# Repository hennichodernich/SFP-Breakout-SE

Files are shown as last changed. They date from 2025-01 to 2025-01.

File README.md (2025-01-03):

# Modified SFP-Breakout-Board

This is a modified version of Anders Wallins SFP Breakout Board https://github.com/aewallin/SFP-Breakout-Board

Like the original this works as a SFP fibre-optical transciever simple breakout board up to at least 1 Gbit/s.

What's changed is that is has
* single-ended TX and RX outputs/inputs with SMA connectors (similar to Anders' SFP2SMA_2018.03 board, but with LVDS/LVPECL converters instead of baluns and op amps)
* different (cheaper) LDO

What's unchanged is
* connector and cage for SFP or SFP+ transciever
* +3V3 power for transciever
* Three status LEDs for TX_FAULT, LOS, and MOD_ABS
* jumpers for SFP rate-select settings.

Licensed under CERN OHL v. 1.2

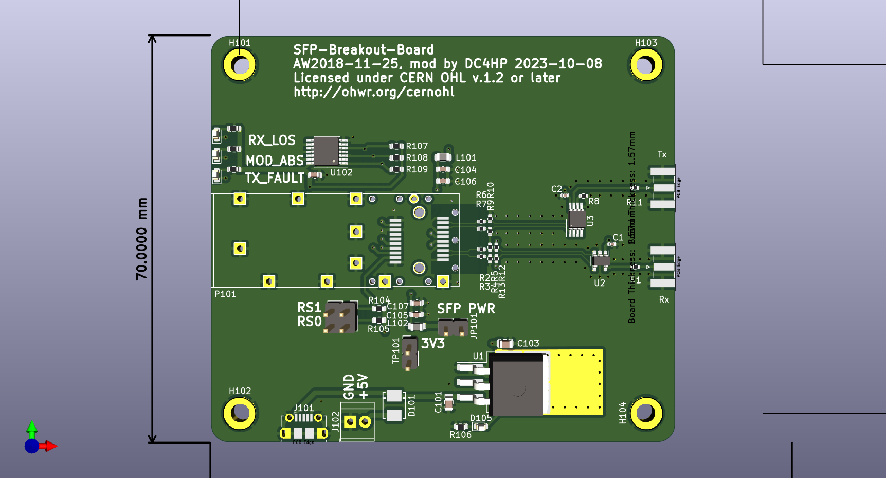
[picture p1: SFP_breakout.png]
PCB PCB image


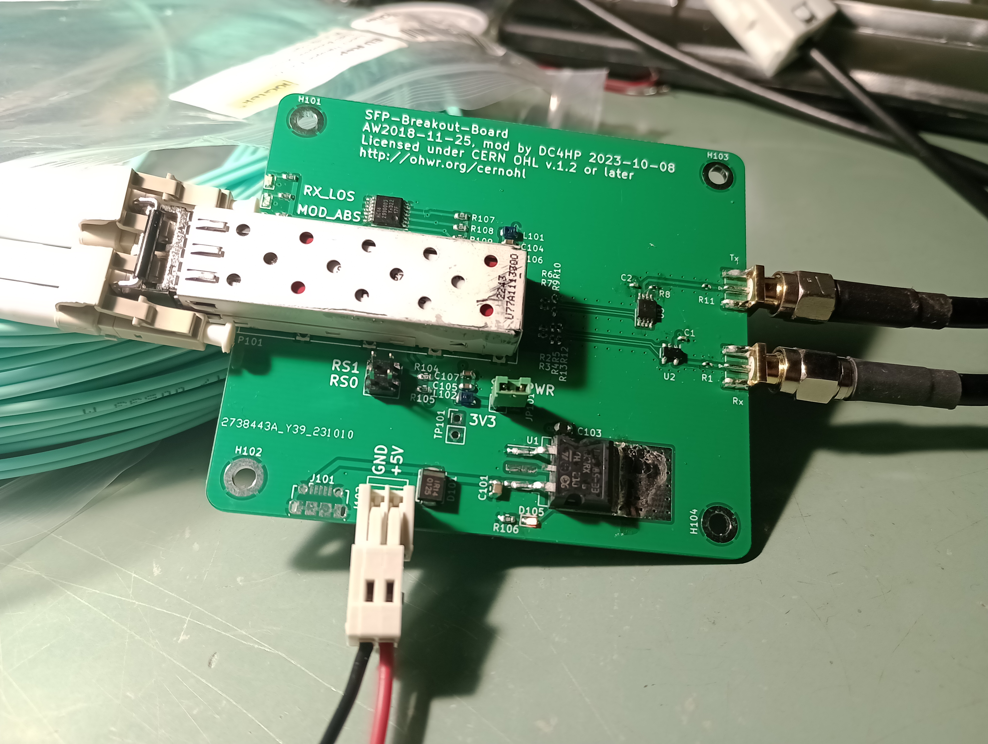
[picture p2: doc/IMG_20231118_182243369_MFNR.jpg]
Board PCB photo


See also these other similar projects:

* https://github.com/aewallin/SFP2SMA_2018.03  single-ended input/output, with op-amp and transformer coupling to SFP
* https://osmocom.org/projects/misc-hardware/wiki/Sfp-experimenter
* https://osmocom.org/projects/misc-hardware/wiki/Sfp-breakout
* Multi-SFP crate https://www.ohwr.org/project/sfp-plus-i2c/wikis/home

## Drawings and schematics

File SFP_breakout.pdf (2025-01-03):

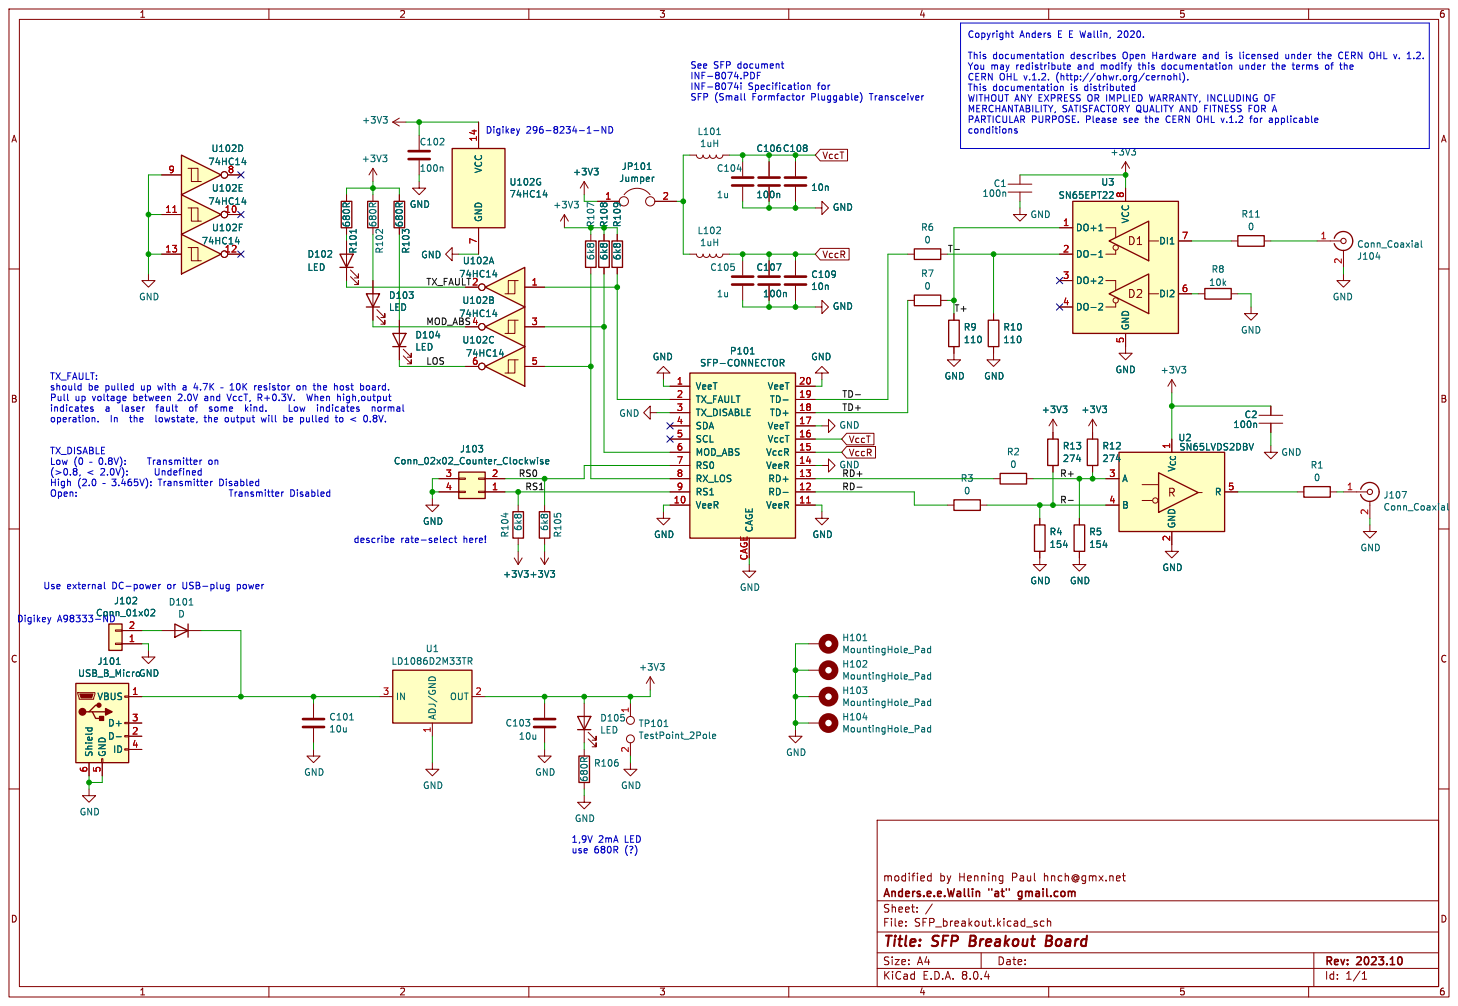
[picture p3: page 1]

PARTICULAR PURPOSE. Please see the CERN OHL v.1.2 for applicable
conditions

Id: 1/1 Title: SFP Breakout Board

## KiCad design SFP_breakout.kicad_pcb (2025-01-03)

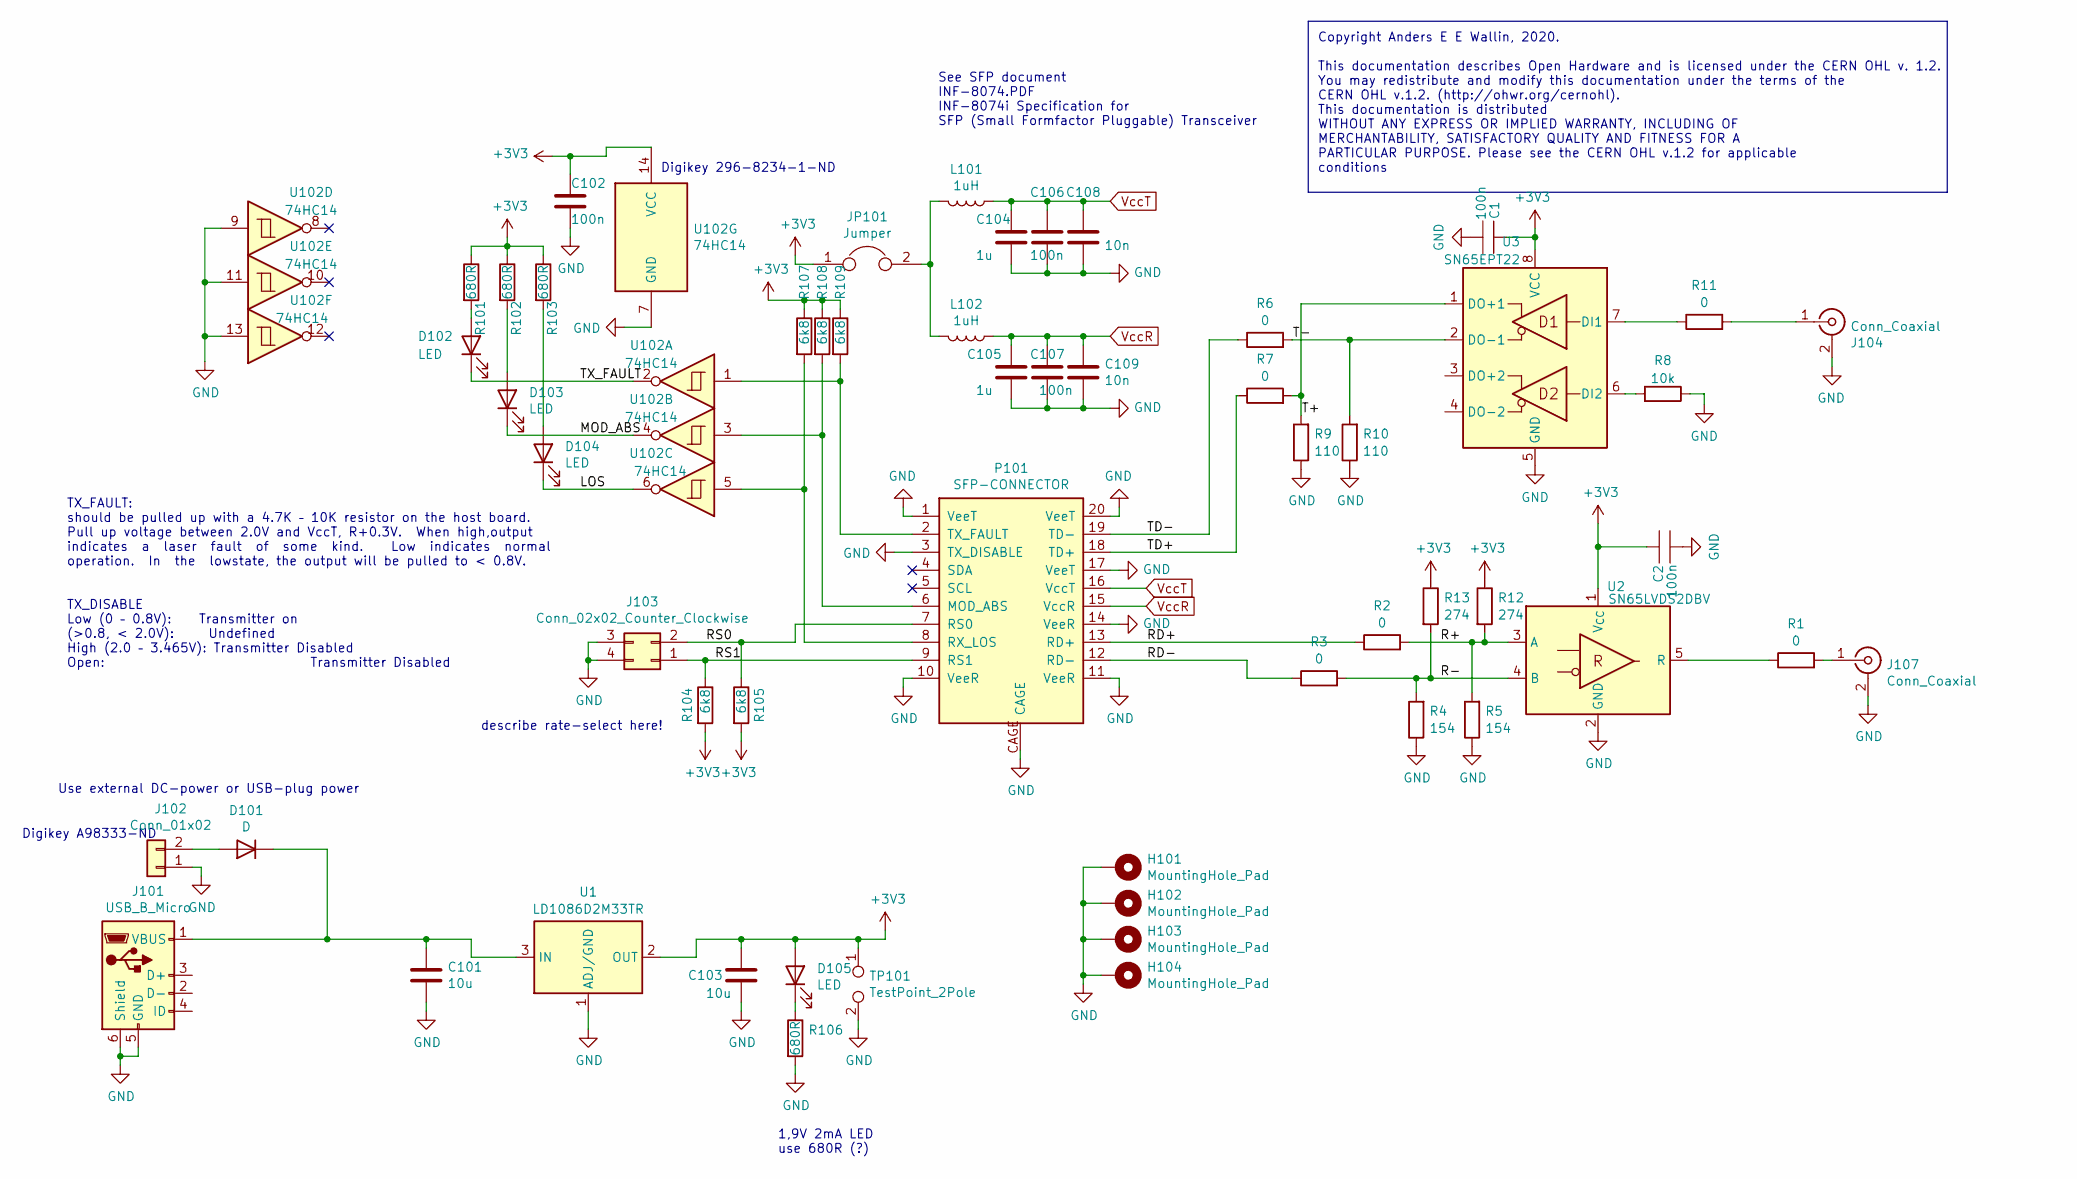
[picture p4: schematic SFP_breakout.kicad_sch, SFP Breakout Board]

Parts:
C1, C2: 100n; C_0402_1005Metric
C101, C103: 10u; C_0805_2012Metric
C102, C106, C107: 100n; C_0603_1608Metric
C104, C105: 1u; C_0603_1608Metric
C108, C109: 10n; C_0603_1608Metric
D101: D; DIODE_DO-214BA
D102, D103, D104, D105: LED; LED_0603_1608Metric
H101, H102, H103, H104: MountingHole_Pad; MountingHole_3.2mm_M3_DIN965_Pad
J101: USB_B_Micro; USB_Micro-B_Molex-105017-0001
J102: Conn_01x02; TerminalBlock_TE_282834-2_1x02_P2.54mm_Horizontal
J103: Conn_02x02_Counter_Clockwise; PinHeader_2x02_P2.54mm_Vertical
J104, J107: Conn_Coaxial; SMA_Samtec_SMA-J-P-X-ST-EM1_EdgeMount
JP101: Jumper; PinHeader_1x02_P2.54mm_Vertical
L101, L102: 1uH; L_0805_2012Metric
P101: SFP-CONNECTOR; Connector_SFP_and_Cage
R1, R2, R3, R6, R7, R11: 0; R_0402_1005Metric
R4, R5: 154; R_0402_1005Metric
R8: 10k; R_0402_1005Metric
R9, R10: 110; R_0402_1005Metric
R12, R13: 274; R_0402_1005Metric
R101, R102, R103, R106: 680R; R_0603_1608Metric
R104, R105, R107, R108, R109: 6k8; R_0603_1608Metric
TP101: TestPoint_2Pole; PinHeader_1x02_P2.54mm_Vertical
U1: LD1086D2M33TR; TO-263-3_TabPin2
U2: SN65LVDS2DBV; SOT-23-5
U3: SN65EPT22; VSSOP-8_3.0x3.0mm_P0.65mm
U102: 74HC14; TSSOP-14_4.4x5mm_P0.65mm

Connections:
+3V3: C1.1, C2.1, C102.1, C103.1, D105.2 (A), JP101.1, R12.1, R13.1, R101.1, R102.1, R103.1, R104.2, R105.2, R107.1, R108.1, R109.1, TP101.1, U1.2 (OUT), U2.1 (V_{CC}), U3.8 (VCC), U102.14 (VCC)
/LOS: D104.1 (K), U102.6
/MOD_ABS: D103.1 (K), U102.4
/R+: R2.2, R5.2, R12.2, U2.3 (A)
/R-: R3.2, R4.2, R13.2, U2.4 (B)
/RD+: P101.13 (RD+), R2.1
/RD-: P101.12 (RD-), R3.1
/RS0: J103.2, P101.7 (RS0), R105.1
/RS1: J103.1, P101.9 (RS1), R104.1
/T+: R7.2, R9.2, U3.1 (DO+1)
/T-: R6.2, R10.2, U3.2 (DO-1)
/TD+: P101.18 (TD+), R7.1
/TD-: P101.19 (TD-), R6.1
/TX_FAULT: D102.1 (K), U102.2
GND: C1.2, C2.2, C101.2, C102.2, C103.2, C104.2, C105.2, C106.2, C107.2, C108.2, C109.2, H101.1, H102.1, H103.1, H104.1, J101.5 (GND), J101.6 (Shield), J102.1, J103.3, J103.4, J104.2 (Ext), J107.2 (Ext), P101.1 (VeeT), P101.3 (TX_DISABLE), P101.10 (VeeR), P101.11 (VeeR), P101.14 (VeeR), P101.17 (VeeT), P101.20 (VeeT), P101.CAGE, R4.1, R5.1, R8.1, R9.1, R10.1, R106.2, TP101.2, U1.1 (ADJ/GND), U2.2 (GND), U3.5 (GND), U102.7 (GND), U102.9, U102.11, U102.13
unnamed: D101.2 (A), J102.2
unnamed: C101.1, D101.1 (K), J101.1 (VBUS), U1.3 (IN)
unnamed: D102.2 (A), R101.2
unnamed: D103.2 (A), R102.2
unnamed: D104.2 (A), R103.2
unnamed: D105.1 (K), R106.1
unnamed: J104.1 (In), R11.2
unnamed: J107.1 (In), R1.2
unnamed: JP101.2, L101.2, L102.2
unnamed: P101.6 (MOD_ABS), R108.2, U102.3
unnamed: P101.8 (RX_LOS), R107.2, U102.5
unnamed: P101.2 (TX_FAULT), R109.2, U102.1
unnamed: R1.1, U2.5 (R)
unnamed: R11.1, U3.7 (DI1)
unnamed: R8.2, U3.6 (DI2)
VccR: C105.1, C107.1, C109.1, L102.1, P101.15 (VccR)
VccT: C104.1, C106.1, C108.1, L101.1, P101.16 (VccT)

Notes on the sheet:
Digikey 296-8234-1-ND
1,9V 2mA LED use 680R (?)
Digikey A98333-ND
describe rate-select here!
Copyright Anders E E Wallin, 2020. This documentation describes Open Hardware and is licensed under the CERN OHL v. 1.2. You may redistribute and modify this documentation under the terms of the CERN OHL v.1.2. (http://ohwr.org/cernohl). This documentation is distributed WITHOUT ANY EXPRESS OR IMPL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
See SFP document INF-8074.PDF INF-8074i Specification for SFP (Small Formfactor Pluggable) Transceiver
TX_FAULT: should be pulled up with a 4.7K – 10K resistor on the host board. Pull up voltage between 2.0V and VccT, R+0.3V. When high,output indicates a laser fault of some kind. Low indicates normal operation. In the lowstate, the output will be pulled to < 0.8V. TX_DISABLE Low (0 – 0.8V): Transmit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
Use external DC-power or USB-plug power

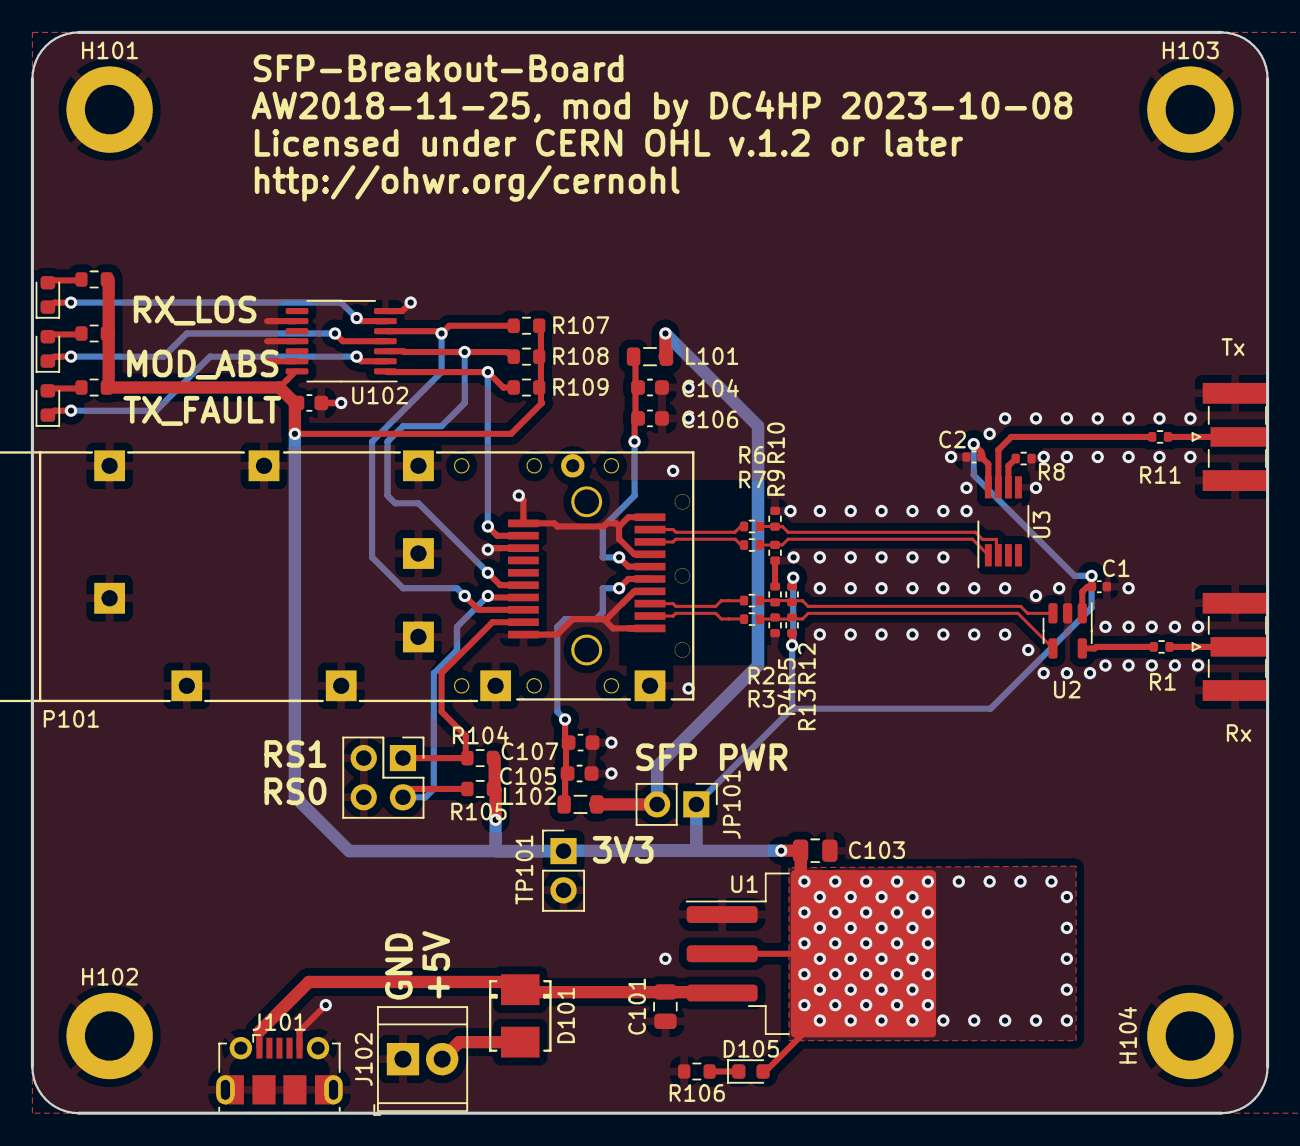
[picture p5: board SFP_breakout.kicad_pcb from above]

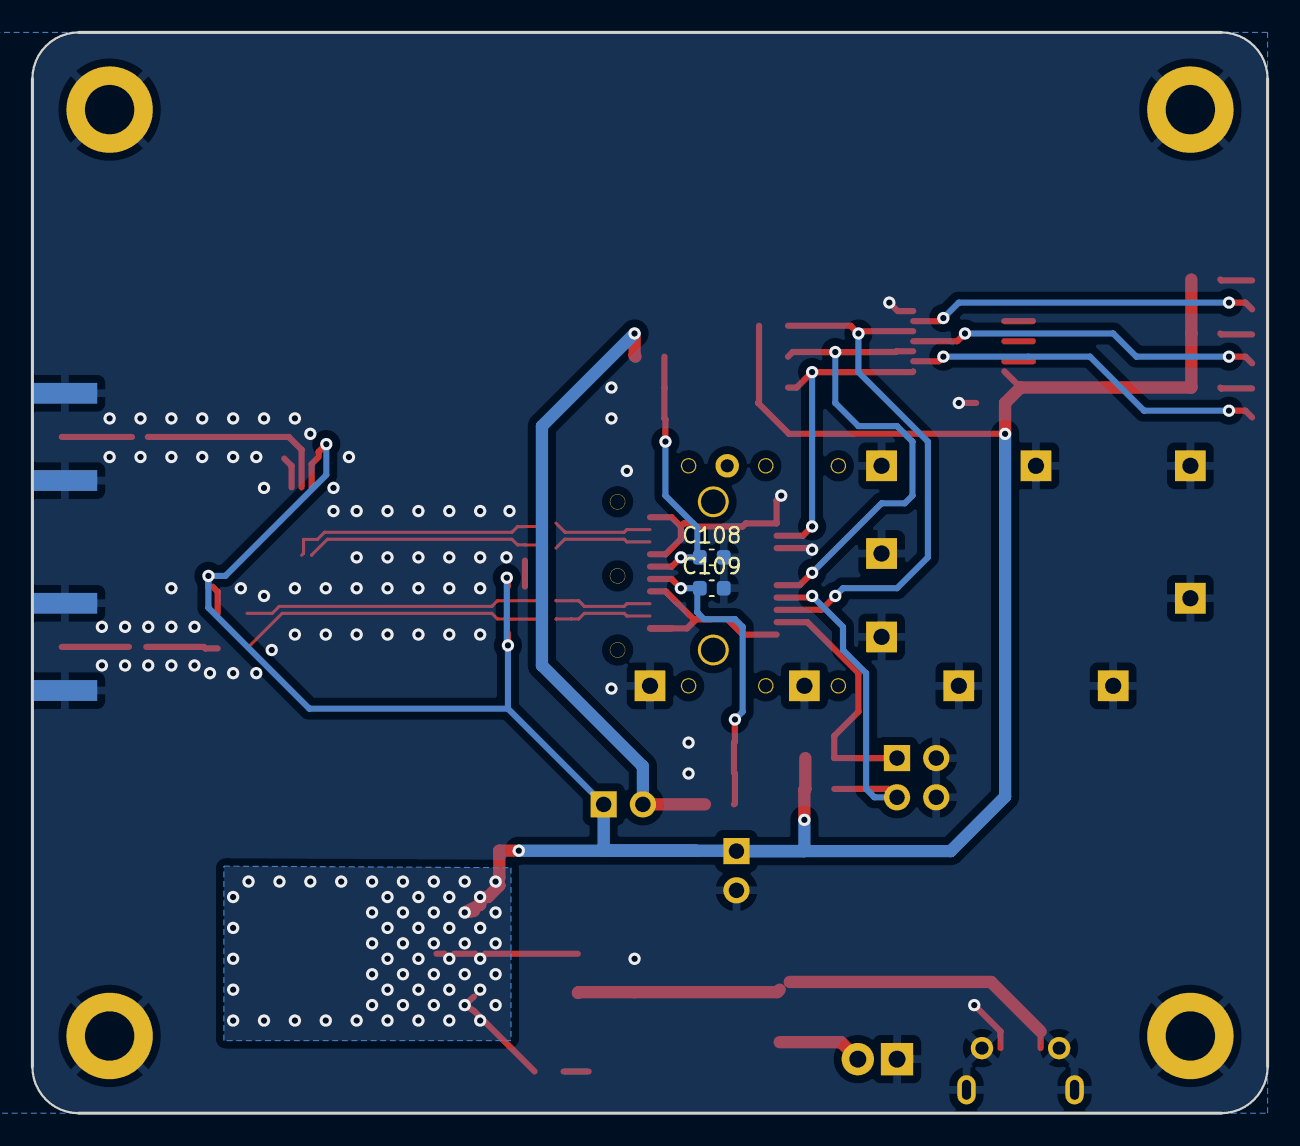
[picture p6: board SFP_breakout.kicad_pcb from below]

Board: 2 copper layers, 80.0 x 70.0 mm, 56 parts (2 on the bottom side), 32 nets.

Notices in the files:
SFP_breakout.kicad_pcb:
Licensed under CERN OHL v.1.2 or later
